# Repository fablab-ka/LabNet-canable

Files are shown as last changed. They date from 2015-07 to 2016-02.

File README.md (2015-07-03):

#LabNet-canable

a fork of canable  
Easy access the LabNet from any PC and integrate Raspberry PIs and Beaglebones in the Infrastructure.

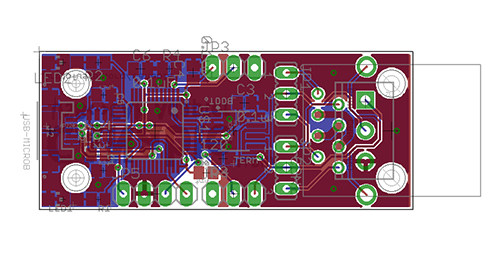
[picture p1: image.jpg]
Image of canable mod


### Original Design 

from Ethan Zonca.  
http://protofusion.org/wordpress/2015/05/the-canable-a-small-usb-to-can-adapter/  
http://hg.protofusion.org/canable  

### modified Firmware of CANtact
https://github.com/normaldotcom/CANtact

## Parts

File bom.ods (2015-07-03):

Qty | Value | Package | Parts |  | Digikey
1 |  | LED-1206 | LED1
1 |  | LED-1206 | LED2
4 |  | 1x03 Pinheader | JP1-JP4
1 |  | 1x04 Pinheader | JP5
1 |  | SCREWTERMINAL-3.5MM-3_LOCK.007S | J3 | http://www.digikey.com/product-detail/en/0393570003/WM7878-ND/946519 | http://www.digikey.com/product-detail/en/0393570003/WM7878-ND/946519
1 | 820 | green-res | R2
1 | 270 | red-res 1/4PWR | R1
3 | 10k | 0805-RES | R4
5 | 0.1uF | 0805-CAP | C1, C2, C3, C4, C6
1 | 120 | 0805-RES | R3
2 | 4.7uF | 0805-CAP | C5, C7
1 | AP2202K-3.3TRG1 | SOT23-5 | U2 | http://www.digikey.com/product-detail/en/AP2202K-3.3TRG1/AP2202K-3.3TRG1DICT-ND/4505286 | http://www.digikey.com/product-detail/en/AP2202K-3.3TRG1/AP2202K-3.3TRG1DICT-ND/4505286
1 | MCP2551 | SO08 | U3 | http://www.digikey.com/product-detail/en/MCP2551-I%2FSN/MCP2551-I%2FSN-ND/509452 | http://www.digikey.com/product-detail/en/MCP2551-I%2FSN/MCP2551-I%2FSN-ND/509452
1 | STM32F042C6T6 | LQFP48 | U$1 | http://www.digikey.com/product-search/en?vendor=0&keywords=497-14648-ND | http://www.digikey.com/product-search/en?vendor=0&keywords=497-14648-ND
1 | USB-MICROB | USB-MICROB | J2 | http://www.digikey.com/product-detail/en/10118192-0001LF/609-4613-1-ND/2785378 | http://www.digikey.com/product-detail/en/10118192-0001LF/609-4613-1-ND/2785378
1 | MEBP_8-8G | MEBP | CON1

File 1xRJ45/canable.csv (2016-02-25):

Qty | Value | Device | Package | Parts | Description | PROD_ID
2 |  | JP2E | JP2 | JP1, JP2 | JUMPER
2 |  | LEDCHIPLED_1206 | CHIPLED_1206 | LED1, LED2 | LED
1 |  | M03SCREW_LOCK | SCREWTERMINAL-3.5MM-3_LOCK.007S | J3 | Header 3
1 |  | MEBP_8-8G | MEBP | CON1 | Reichelt RJ45 geschirmt MEBP 8-8G
2 |  | PINHD-1X3 | 1X03 | JP3, JP4 | PIN HEADER
1 |  | PINHD-1X4 | 1X04 | JP5 | PIN HEADER
3 |  | R-EU_R0805 | R0805 | R1, R2, R4 | RESISTOR, European symbol
5 | 0.1uF | C-EUC0805 | C0805 | C1, C2, C3, C4, C6 | CAPACITOR, European symbol
1 | 120 | R-EU_R0805 | R0805 | R3 | RESISTOR, European symbol
2 | 4.7uF | C-EUC0805 | C0805 | C5, C7 | CAPACITOR, European symbol
1 | AP2202K-3.3TRG1 | MIC52053.3V | SOT23-5 | U2 | MIC5205 150mA vreg | VREG-00822
1 | MCP2551 | MCP2551 | SO08 | U3 | CAN transceiver | IC-09907
1 | STM32F042C6T6 | STM32F042C6T6 | LQFP48 | U$1
1 | USB-MICROB | USB-MICROB | USB-MICROB | J2 | USB Connectors | CONN-09505

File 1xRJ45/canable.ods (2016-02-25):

X | Qty | Value | Device | Package | Parts | Description | Reichelt | Digikey | Preis | Summe
 | 2 |  | LEDCHIPLED_1206 | CHIPLED_1206 | LED1, LED2 | LED | SMD-LED 1206 GN |  | 0,1 | 0,2
 | 1 |  | M03SCREW_LOCK | SCREWTERMINAL-3.5MM-3_LOCK.007S | J3 | Header 3 |  |  |  | 0
 | 1 |  | MEBP_8-8G | MEBP | CON1 | Reichelt RJ45 geschirmt MEBP 8-8G | MEBP 8-8G |  | 0,55 | 0,55
 | 2 |  |  |  |  | Jumper | JUMPER 2,54GL SW |  | 0,05 | 0,1
 | 0 |  | JP2E | JP2 | JP1, JP2 | PIN HEADER |  |  |  | 0
 | 0 |  | PINHD-1X3 | 1X03 | JP3, JP4 | PIN HEADER |  |  |  | 0
 | 0 |  | PINHD-1X4 | 1X04 | JP5 | PIN HEADER |  |  |  | 0
 | 1 |  | PINHD-1X36 |  | JP1, JP2,JP5, JP3, JP4 | PIN HEADER | SL 1X36G 2,54 |  | 0,16 | 0,16
 | 1 | 10k | R-EU_R0805 | R0805 | R4 | RESISTOR, European symbol | SMD-0805 10,0K |  | 0,103 | 0,103
 | 2 | 220 | R-EU_R0805 | R0805 | R1, R2 | RESISTOR, European symbol | SMD-0805 220 |  | 0,1 | 0,2
 | 5 | 0.1uF | C-EUC0805 | C0805 | C1, C2, C3, C4, C6 | CAPACITOR, European symbol | X7R-G0805 100N |  | 0,04 | 0,2
 | 1 | 120 | R-EU_R0805 | R0805 | R3 | RESISTOR, European symbol | SMD-0805 120 |  | 0,1 | 0,1
 | 2 | 4.7uF | C-EUC0805 | C0805 | C5, C7 | CAPACITOR, European symbol | X7R-G0805 4,7/16 |  | 0,16 | 0,32
 | 0 | AP2202K-3.3TRG1 | MIC52053.3V | SOT23-5 | U2 | MIC5205 150mA vreg | - |  |  | 0
 | 1 | TS 5205 CX533 | MIC52053.3V | SOT23-5 | U2 | LDO-U-Reg +3,3V 0,15A SOT23-5 | TS 5205 CX533 |  | 0,25 | 0,25
 | 0 | MCP2551 | MCP2551 | SO08 | U3 | CAN transceiver | MCP 2551-I/P |  | 1,1 | 0
 | 0 | STM32F042C6T6 | STM32F042C6T6 | LQFP48 | U$1 |  | - |  | 3,4 | 0
 | 1 | USB-MICROB | USB-MICROB | USB-MICROB | J2 | USB Connectors | MIC USB BBU |  | 0,58 | 0,58
 |  |  |  |  |  |  |  |  |  | 2,763

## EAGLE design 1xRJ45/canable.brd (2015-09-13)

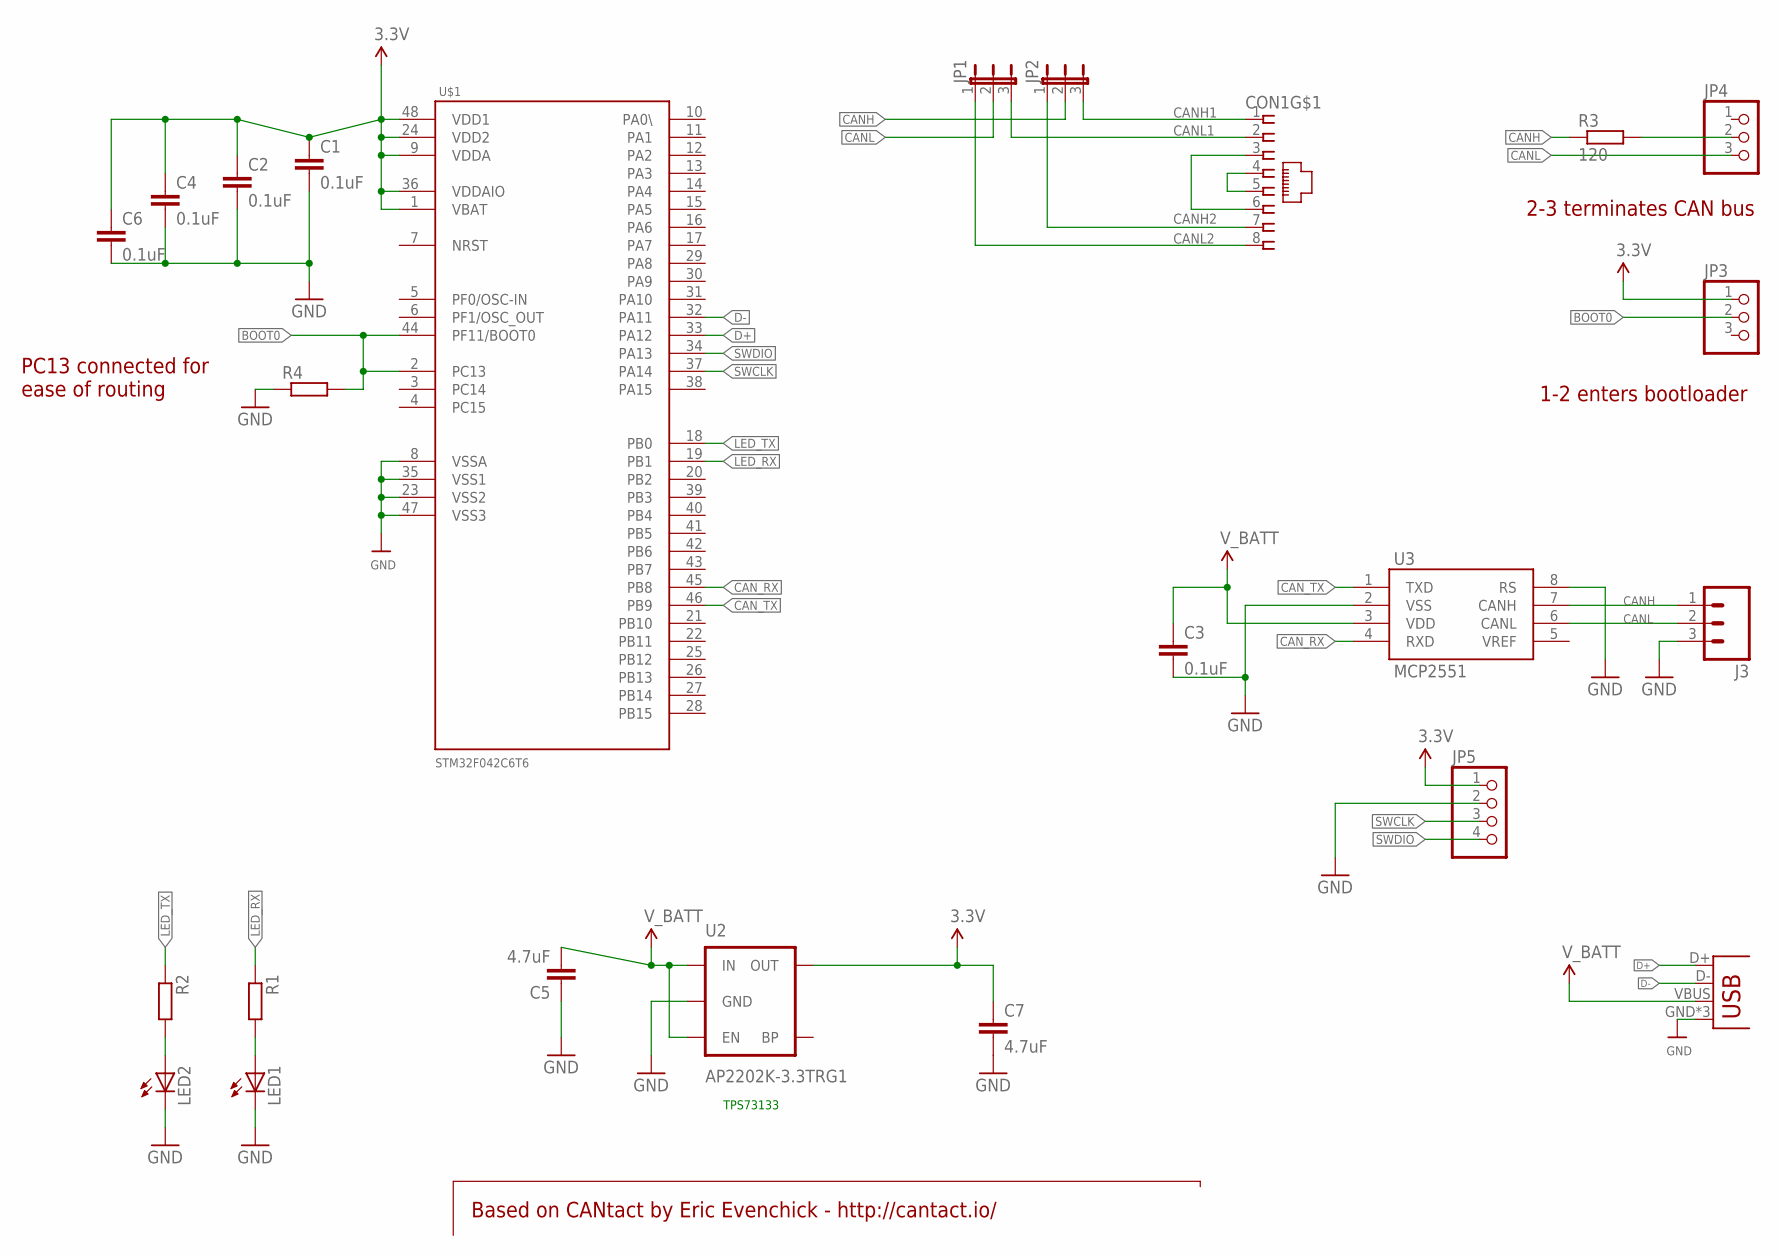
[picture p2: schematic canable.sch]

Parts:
C1, C2, C3, C4, C6: 0.1uF; C0805
C5, C7: 4.7uF; C0805
CON1: MEBP_8-8G; MEBP
J2: USB-MICROB
J3: M03SCREW_LOCK; SCREWTERMINAL-3.5MM-3_LOCK.007S
JP1, JP2: JP2E; JP2
JP3, JP4: PINHD-1X3; 1X03
JP5: PINHD-1X4; 1X04
LED1, LED2: LEDCHIPLED_1206; CHIPLED_1206
R1, R2, R4: R-EU_R0805; R0805
R3: 120; R0805
U2: AP2202K-3.3TRG1; SOT23-5
U3: MCP2551; SO08
U$1: STM32F042C6T6; LQFP48

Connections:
3.3V: C1.1, C2.1, C4.1, C6.1, C7.1, JP3.1, JP5.1, U2.5 (OUT), U$1.1 (VBAT), U$1.9 (VDDA), U$1.24 (VDD2), U$1.36 (VDDAIO), U$1.48 (VDD1)
BOOT0: JP3.2, R4.2, U$1.2 (PC13), U$1.44 (PF11/BOOT0)
CANH: J3.1, JP2.2, R3.1, U3.7 (CANH)
CANH1: CON1.1, JP2.3
CANH2: CON1.7, JP2.1
CANL: J3.2, JP1.2, JP4.3, U3.6 (CANL)
CANL1: CON1.2, JP1.3
CANL2: CON1.8, JP1.1
CAN_RX: U3.4 (RXD), U$1.45 (PB8)
CAN_TX: U3.1 (TXD), U$1.46 (PB9)
D+: J2.D+, U$1.33 (PA12)
D-: J2.D-, U$1.32 (PA11)
FGND: CON1.T1 (FGND), CON1.T2 (FGND)
GND: C1.2, C2.2, C3.2, C4.2, C5.1, C6.2, C7.2, J2.GND, J2.MT1 (GND), J2.MT2 (GND), J3.3, JP5.2, LED1.C, LED2.C, R4.1, U2.2 (GND), U3.2 (VSS), U3.8 (RS), U$1.8 (VSSA), U$1.23 (VSS2), U$1.35 (VSS1), U$1.47 (VSS3)
LED_RX: R1.1, U$1.19 (PB1)
LED_TX: R2.1, U$1.18 (PB0)
unnamed: CON1.3, CON1.6
unnamed: LED2.A, R2.2
unnamed: JP4.2, R3.2
unnamed: CON1.4, CON1.5
unnamed: LED1.A, R1.2
SWCLK: JP5.3, U$1.37 (PA14)
SWDIO: JP5.4, U$1.34 (PA13)
V_BATT: C3.1, C5.2, J2.VBUS, U2.1 (IN), U2.3 (EN), U3.3 (VDD)

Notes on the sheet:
Based on CANtact by Eric Evenchick - http://cantact.io/
PC13 connected for ease of routing
2-3 terminates CAN bus
1-2 enters bootloader
TPS73133

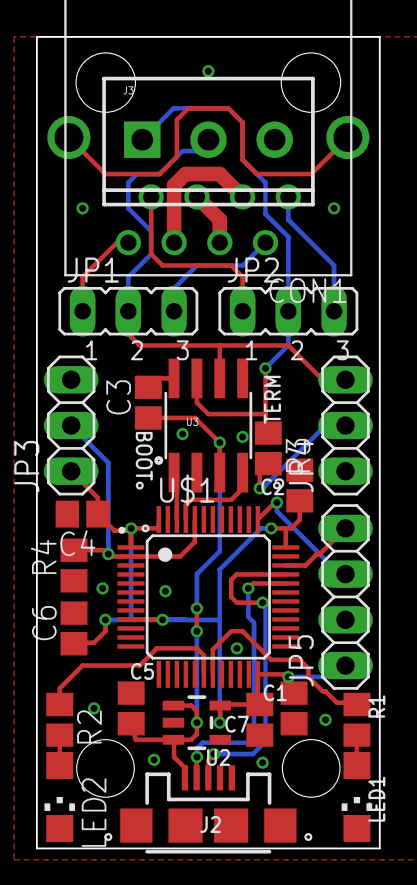
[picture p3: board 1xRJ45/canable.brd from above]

Board: 2 copper layers, 19.1 x 45.1 mm, 25 parts (1 on the bottom side), 24 nets.

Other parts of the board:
U$2: CANABLE-LOGO

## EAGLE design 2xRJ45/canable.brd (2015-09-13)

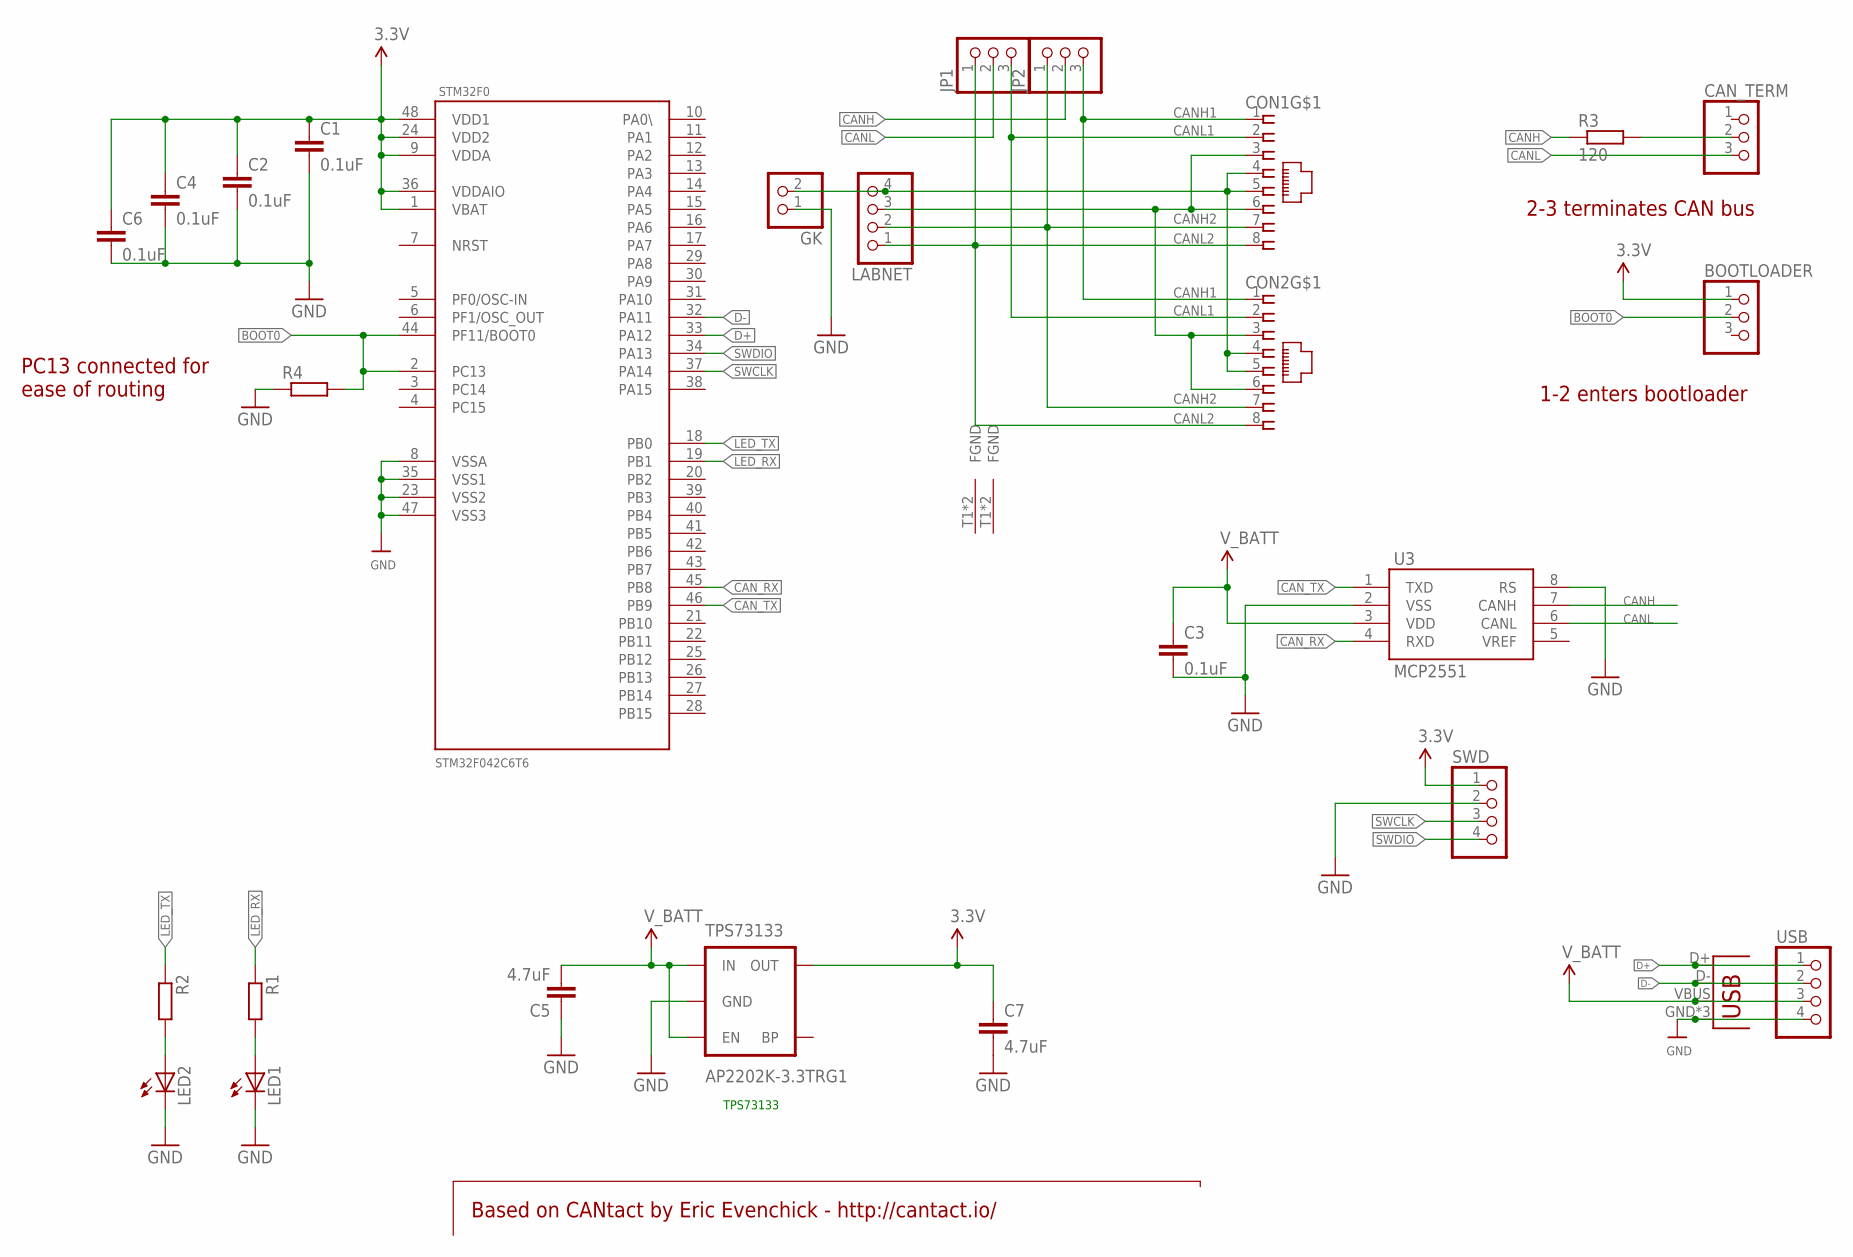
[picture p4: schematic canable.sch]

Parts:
BOOTLOADER: PINHD-1X3; 1X03
C1, C2, C3, C4, C6: 0.1uF; C0805
C5, C7: 4.7uF; C0805
CAN_TERM: PINHD-1X3; 1X03
CON1, CON2: MEBP_8-8G; MEBP
GK: PINHD-1X2; 1X02
J2: USB-MICROB
JP1, JP2: PINHD-1X3; 1X03
LABNET: PINHD-1X4; 1X04
LED1, LED2: LEDCHIPLED_1206; CHIPLED_1206
R1, R2, R4: R-EU_R0805; R0805
R3: 120; R0805
STM32F0: STM32F042C6T6; LQFP48
SWD: PINHD-1X4; 1X04
TPS73133: AP2202K-3.3TRG1; SOT23-5
U3: MCP2551; SO08
USB: PINHD-1X4; 1X04

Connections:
3.3V: BOOTLOADER.1, C1.1, C2.1, C4.1, C6.1, C7.1, STM32F0.1 (VBAT), STM32F0.9 (VDDA), STM32F0.24 (VDD2), STM32F0.36 (VDDAIO), STM32F0.48 (VDD1), SWD.1, TPS73133.5 (OUT)
BOOT0: BOOTLOADER.2, R4.2, STM32F0.2 (PC13), STM32F0.44 (PF11/BOOT0)
CANH: JP2.2, R3.1, U3.7 (CANH)
CANH1: CON1.1, CON2.1, JP2.3
CANH2: CON1.7, CON2.7, JP2.1, LABNET.2
CANL: CAN_TERM.3, JP1.2, U3.6 (CANL)
CANL1: CON1.2, CON2.2, JP1.3
CANL2: CON1.8, CON2.8, JP1.1, LABNET.1
CAN_RX: STM32F0.45 (PB8), U3.4 (RXD)
CAN_TX: STM32F0.46 (PB9), U3.1 (TXD)
D+: J2.D+, STM32F0.33 (PA12), USB.1
D-: J2.D-, STM32F0.32 (PA11), USB.2
FGND: CON1.T1 (FGND), CON1.T2 (FGND), CON2.T1 (FGND), CON2.T2 (FGND)
GND: C1.2, C2.2, C3.2, C4.2, C5.1, C6.2, C7.2, GK.1, J2.GND, J2.MT1 (GND), J2.MT2 (GND), LED1.C, LED2.C, R4.1, STM32F0.8 (VSSA), STM32F0.23 (VSS2), STM32F0.35 (VSS1), STM32F0.47 (VSS3), SWD.2, TPS73133.2 (GND), U3.2 (VSS), U3.8 (RS), USB.4
LED_RX: R1.1, STM32F0.19 (PB1)
LED_TX: R2.1, STM32F0.18 (PB0)
unnamed: LED2.A, R2.2
unnamed: CAN_TERM.2, R3.2
unnamed: CON1.3, CON1.6, CON2.3, CON2.6, LABNET.3
unnamed: CON1.4, CON1.5, CON2.4, CON2.5, GK.2, LABNET.4
unnamed: LED1.A, R1.2
SWCLK: STM32F0.37 (PA14), SWD.3
SWDIO: STM32F0.34 (PA13), SWD.4
V_BATT: C3.1, C5.2, J2.VBUS, TPS73133.1 (IN), TPS73133.3 (EN), U3.3 (VDD), USB.3

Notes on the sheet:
Based on CANtact by Eric Evenchick - http://cantact.io/
PC13 connected for ease of routing
2-3 terminates CAN bus
1-2 enters bootloader
TPS73133

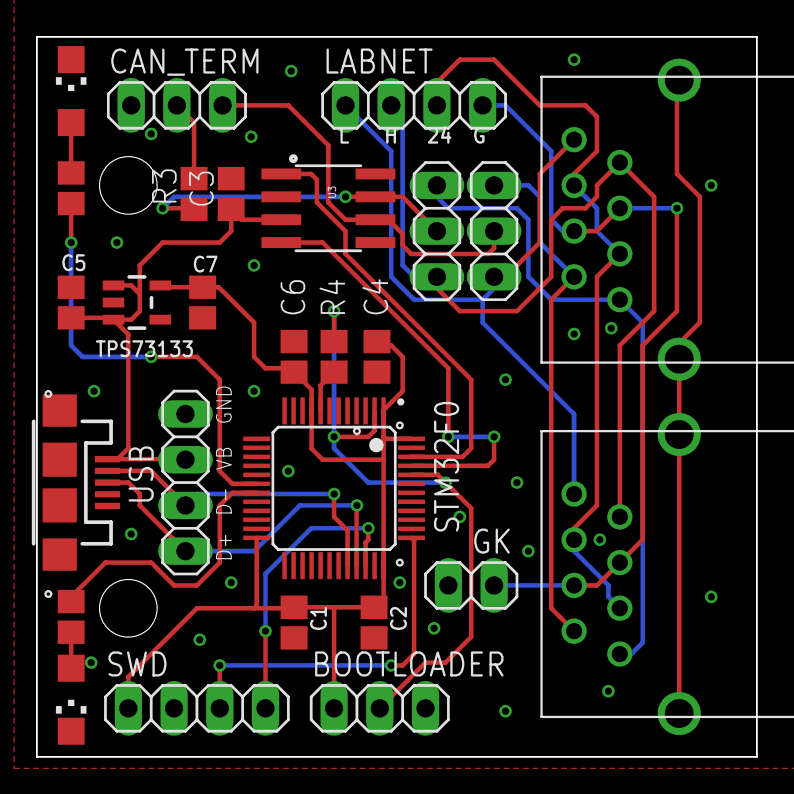
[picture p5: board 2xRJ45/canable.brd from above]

Board: 2 copper layers, 40.0 x 40.0 mm, 27 parts (0 on the bottom side), 24 nets.

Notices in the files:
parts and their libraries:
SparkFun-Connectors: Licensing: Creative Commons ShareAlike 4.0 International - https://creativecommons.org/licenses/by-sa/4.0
